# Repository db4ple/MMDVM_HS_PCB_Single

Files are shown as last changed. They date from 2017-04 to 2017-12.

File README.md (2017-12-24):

# MMDVM_HS_PCB_Single
Single Sided PCB for MMDVM Hotspot with RF7021SE module and Blue Pill STM32DUINO

This project provides a simple, singled sided PCB for the [MMDVM_HS Hotspot main repo](https://github.com/juribeparada/MMDVM_HS). 
Can be easily made using toner transfer, has very few wires. Just order the components (RF7021SE from Aliexpress and Blue Pill 
STM32DUINO clone) and put on board. Do not forget to replace the RF7021SE standard oscillator with a supported TCXO.

The second pcb design called stick is much smaller, and has a more logical led layout. But it requires a few more via wires if made as a single sided board. 
Most connecting wires are only used if the optional connectors are used. 
The single pin connector in the middle of the board is in fact a bottom / top ground plane connection for a two sided design. No need to use it on a single sided pcb.

© DB4PLE
Licensed under CC-BY-SA 3.0

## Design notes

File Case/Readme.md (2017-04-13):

This is a simple 3D printable case for the board. Best if printed in something more or less transparent. 
In this case the notification LEDs can be seen easily. 

You can either use the Raspberry Pi Zero lid and base (if you run the hotspot using an RPi Zero W) OR the simple base (if you connect the hotspot to an external computer via USB).

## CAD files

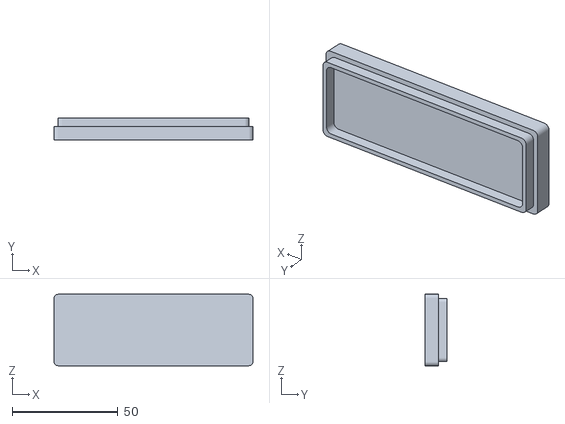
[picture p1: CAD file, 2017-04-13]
Case/Hotspot_base.stl
94.0 x 10.6 x 33.8

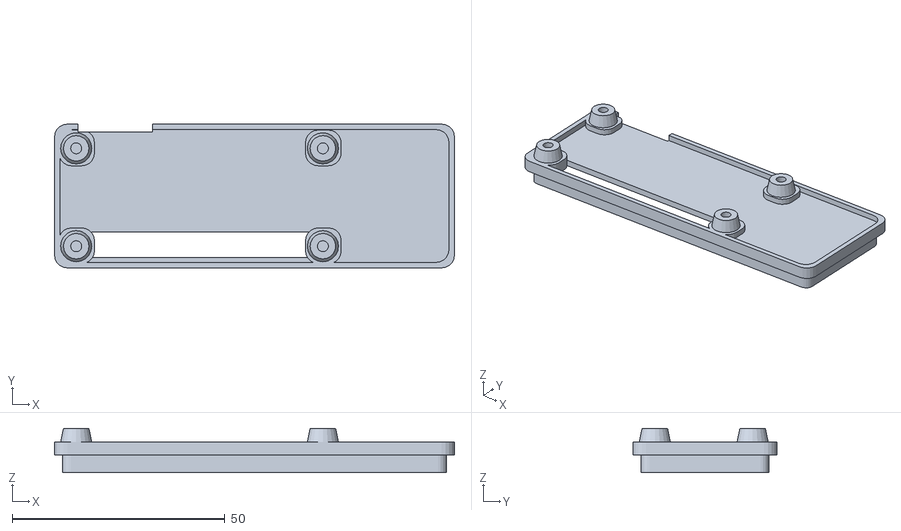
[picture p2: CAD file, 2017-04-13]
Case/Hotspot_RPIZW_lid.stl
94.0 x 33.8 x 10.4

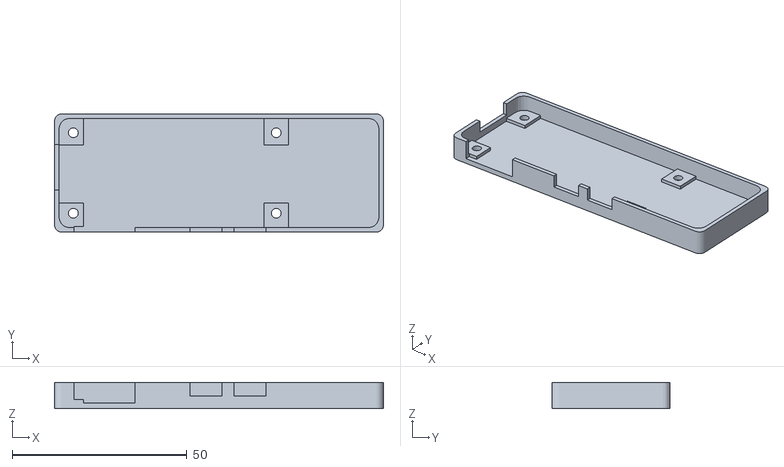
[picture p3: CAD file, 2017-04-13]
Case/Hotspot_RPIZW_base.stl
94.0 x 33.8 x 7.45

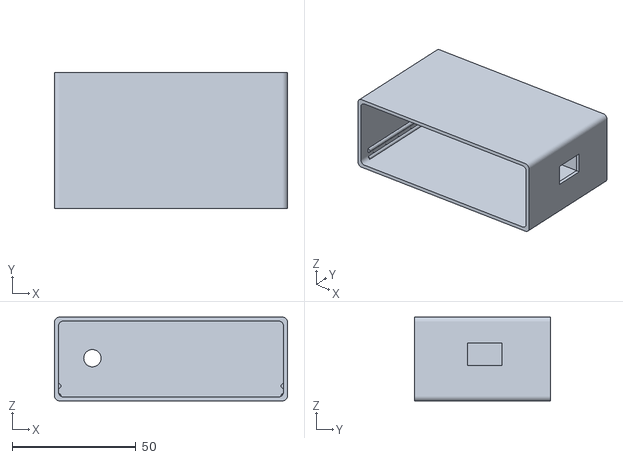
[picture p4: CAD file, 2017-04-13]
Case/Hotspot.stl
94.0 x 54.9 x 33.8

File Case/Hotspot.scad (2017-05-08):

// the rounded cube module comes from
// https://gist.github.com/groovenectar/92174cb1c98c1089347e

$fs = 0.15;


module roundcylinder(d=1,h=10)
{
    translate([0,0,d/2])
    hull()
    {
    sphere(d=d);
    
    translate([0,0,h-d]) sphere(d=d);
    }
}

module roundedcube(size = [1, 1, 1], center = false, radius = 0.5, apply_to = "all") {
	// If single value, convert to [x, y, z] vector
	size = (size[0] == undef) ? [size, size, size] : size;

	translate_min = radius;
	translate_xmax = size[0] - radius;
	translate_ymax = size[1] - radius;
	translate_zmax = size[2] - radius;

	diameter = radius * 2;

	obj_translate = (center == false) ?
		[0, 0, 0] : [
			-(size[0] / 2),
			-(size[1] / 2),
			-(size[2] / 2)
		];

	translate(v = obj_translate) {
		hull() {
			for (translate_x = [translate_min, translate_xmax]) {
				x_at = (translate_x == translate_min) ? "min" : "max";
				for (translate_y = [translate_min, translate_ymax]) {
					y_at = (translate_y == translate_min) ? "min" : "max";
					for (translate_z = [translate_min, translate_zmax]) {
						z_at = (translate_z == translate_min) ? "min" : "max";

						translate(v = [translate_x, translate_y, translate_z])
						if (
							(apply_to == "all") ||
							(apply_to == "xmin" && x_at == "min") || (apply_to == "xmax" && x_at == "max") ||
							(apply_to == "ymin" && y_at == "min") || (apply_to == "ymax" && y_at == "max") ||
							(apply_to == "zmin" && z_at == "min") || (apply_to == "zmax" && z_at == "max")
						) {
							sphere(r = radius);
						} else {
							rotate = 
								(apply_to == "xmin" || apply_to == "xmax" || apply_to == "x") ? [0, 90, 0] : (
								(apply_to == "ymin" || apply_to == "ymax" || apply_to == "y") ? [90, 90, 0] :
								[0, 0, 0]
							);
							rotate(a = rotate)
							cylinder(h = diameter, r = radius, center = true);
						}
					}
				}
			}
		}
	}
}

// end roundedcube contribution


// actual case starts here
// $fn=100;

rpizw_pcb_h = 1.4;
rpizw_pcb_w = 65;
rpizw_pcb_l = 30;

usbpower_offset = 54.0;
usbusb_offset = 41.4;
usb_length = 8.0;
usb_h = 3.0;

hdmi_offset = 12.4;
hdmi_length = 12.0;
hdmi_h = 3.4;




tol = 0.3;
pcb_h = 1.6;
pcb_t = 5;
pcb_w = 48.260;
//pcb_l = 87.860;
pcb_l = 90.86;

stm_h = 11.35;
stm_w = 22.860;
stm_l = 53.430;

stm_usb_w = 14;
stm_usb_h = 9;    
rf_w = 27;    

wall = 1.6;
box_h=30 + 2* tol;
down=-13.5;

extend_h = 32;


module holder()
{
    dia = 2;
    translate([pcb_l,0,-dia/2-0.4]) rotate([270,0,0]) cylinder(d=2,h=pcb_w + wall);
    translate([0,0,-dia/2-0.4]) rotate([270,0,0]) cylinder(d=2,h=pcb_w + wall);
    
    translate([pcb_l,0,dia/2+pcb_h]) rotate([270,0,0]) cylinder(d=2,h=pcb_w + wall);
    translate([0,0,dia/2+pcb_h]) rotate([270,0,0]) cylinder(d=2,h=pcb_w + wall);

}
module pcb()
{
    cube([pcb_l,pcb_w,pcb_h]);
}
module rf7021()
{
    rf_pcb_h = 1;
    ant_dia = 7;
    sma_pin_dia = 1.25;
    translate([-rf_w/2,0,0])cube([rf_w,pcb_w,rf_pcb_h]);
    translate([0,35,rf_pcb_h+sma_pin_dia/2]) rotate([270,0,0]) cylinder(d=ant_dia,h=30);
}

module stm()
{
    cube([stm_l,stm_w,stm_h]);
    translate([stm_l-2,(stm_w-stm_usb_w)/2 ,stm_h-stm_usb_h/2+2.5]) cube([20,stm_usb_w,stm_usb_h]);   
}

module hotspot()
{
    pcb();
    translate([12.7+1,0,pcb_h+10.6])rf7021();
    translate([pcb_l - stm_l,(pcb_w-stm_w)/2,pcb_h]) stm();
}




//translate([-wall,-wall,-wall]) cube([pcb_l+2*wall,pcb_w+2*wall,box_h+wall]);
// hotspot();
// rf7021();
// stm();

module assembly()
{

    translate([-pcb_l/2,-pcb_w/2+wall/2+extend_h/2,down]) 
    {
           // hotspot();    

        holder();
    }

    difference()
    {
        color("Orange")
        translate([0,wall,0]) roundedcube([pcb_l+2*wall, pcb_w+wall+extend_h, box_h+2*wall], true, 2, "y");
   
        {
        roundedcube([pcb_l, pcb_w+wall+extend_h, box_h], true, 2, "y");
        translate([-pcb_l/2,-pcb_w/2+extend_h/2+wall/2,down]) 
        {
            hotspot();    
        }
        
    //    translate([0,-10,0]) cube([pcb_l-2,pcb_w+10,box_h-wall]);
        }
    }
}


module assembly_base()
{
    base_h = 3.6;
    color("Orange")
    // translate([0,-wall/2,0]) roundedcube([pcb_l+2*wall, wall, box_h+2*wall], true, 2, "y");    
    difference() {
    translate([0,base_h/2,0]) roundedcube([pcb_l-2*tol, base_h, box_h-2*tol], true, 2, "y");
    translate([0,base_h/2,0]) roundedcube([pcb_l-wall-2*tol, base_h+5, box_h-wall-2*tol], true, 2, "y");
    }
}

// translate([(pcb_l-2*tol)/2+tol,(box_h-2*tol)/2+tol,-4.7]) rotate ([90,0,0]) assembly_base();



module pizw()
{

    difference()
    {
        cube([30,65,rpizw_pcb_h]);
        translate([0,0,-0.1])
        {    
            translate([3.5,3.5]) cylinder(d=2.75,h=4);
            translate([rpizw_pcb_l-3.5,3.5]) cylinder(d=2.75,h=4);
            translate([rpizw_pcb_l-3.5,rpizw_pcb_w-3.5]) cylinder(d=2.75,h=4);
            translate([3.5,rpizw_pcb_w-3.5]) cylinder(d=2.75,h=4);
        }
    }
translate([-3,rpizw_pcb_w-usbusb_offset-usb_length/2-tol,rpizw_pcb_h-0.2]) cube([10,usb_length+2*tol,usb_h+2*tol]);
translate([-3,rpizw_pcb_w-usbpower_offset-usb_length/2-tol,rpizw_pcb_h-0.2]) cube([10,usb_length+2*tol,usb_h+2*tol]);
translate([-3,rpizw_pcb_w-hdmi_offset-hdmi_length/2,rpizw_pcb_h-0.2]) cube([10,hdmi_length,hdmi_h+2*tol]);
}

module pizw_holder()
{
    dia = 2;
    translate([-rpizw_pcb_w/2,0,-30/2])
    {
        translate([0,-dia/2],0) rotate([90,0,90]) roundcylinder(d=dia,h=rpizw_pcb_w);
        translate([0,rpizw_pcb_h+dia/2],0) rotate([90,0,90]) roundcylinder(d=dia,h=rpizw_pcb_w);
    }
    translate([-rpizw_pcb_w/2,0,30/2])
    {
        translate([0,-dia/2],0) rotate([90,0,90]) roundcylinder(d=dia,h=19);
        translate([36,-dia/2],0) rotate([90,0,90]) roundcylinder(d=dia,h=29);
        // translate([21,rpizw_pcb_h+dia/2],0) rotate([90,0,90]) roundcylinder(d=dia,h=5);
        translate([rpizw_pcb_w-5,rpizw_pcb_h+dia/2],0) rotate([90,0,90]) roundcylinder(d=dia,h=5);
        translate([0,rpizw_pcb_h+dia/2],0) rotate([90,0,90]) roundcylinder(d=dia,h=5);
    }
    
    // translate([pcb_l,0,dia/2+pcb_h]) rotate([270,0,0]) cylinder(d=2,h=pcb_w + wall);
    // translate([0,0,dia/2+pcb_h]) rotate([270,0,0]) cylinder(d=2,h=pcb_w + wall);

}


module all()
{
    rpizw_down = 2;
    difference()
    {
        union()
        {
            assembly();
            translate([0,-box_h-rpizw_down,0])    pizw_holder();
        }
    translate([0,-box_h-rpizw_down,0])
    {
        translate([rpizw_pcb_w/2,0,rpizw_pcb_l/2])rotate([0,90,90]) color("red") pizw();
    }
}

}


difference()
{
    all();
//    translate([-50,-23,-60])cube([100,200,100]);
}

// pizw();

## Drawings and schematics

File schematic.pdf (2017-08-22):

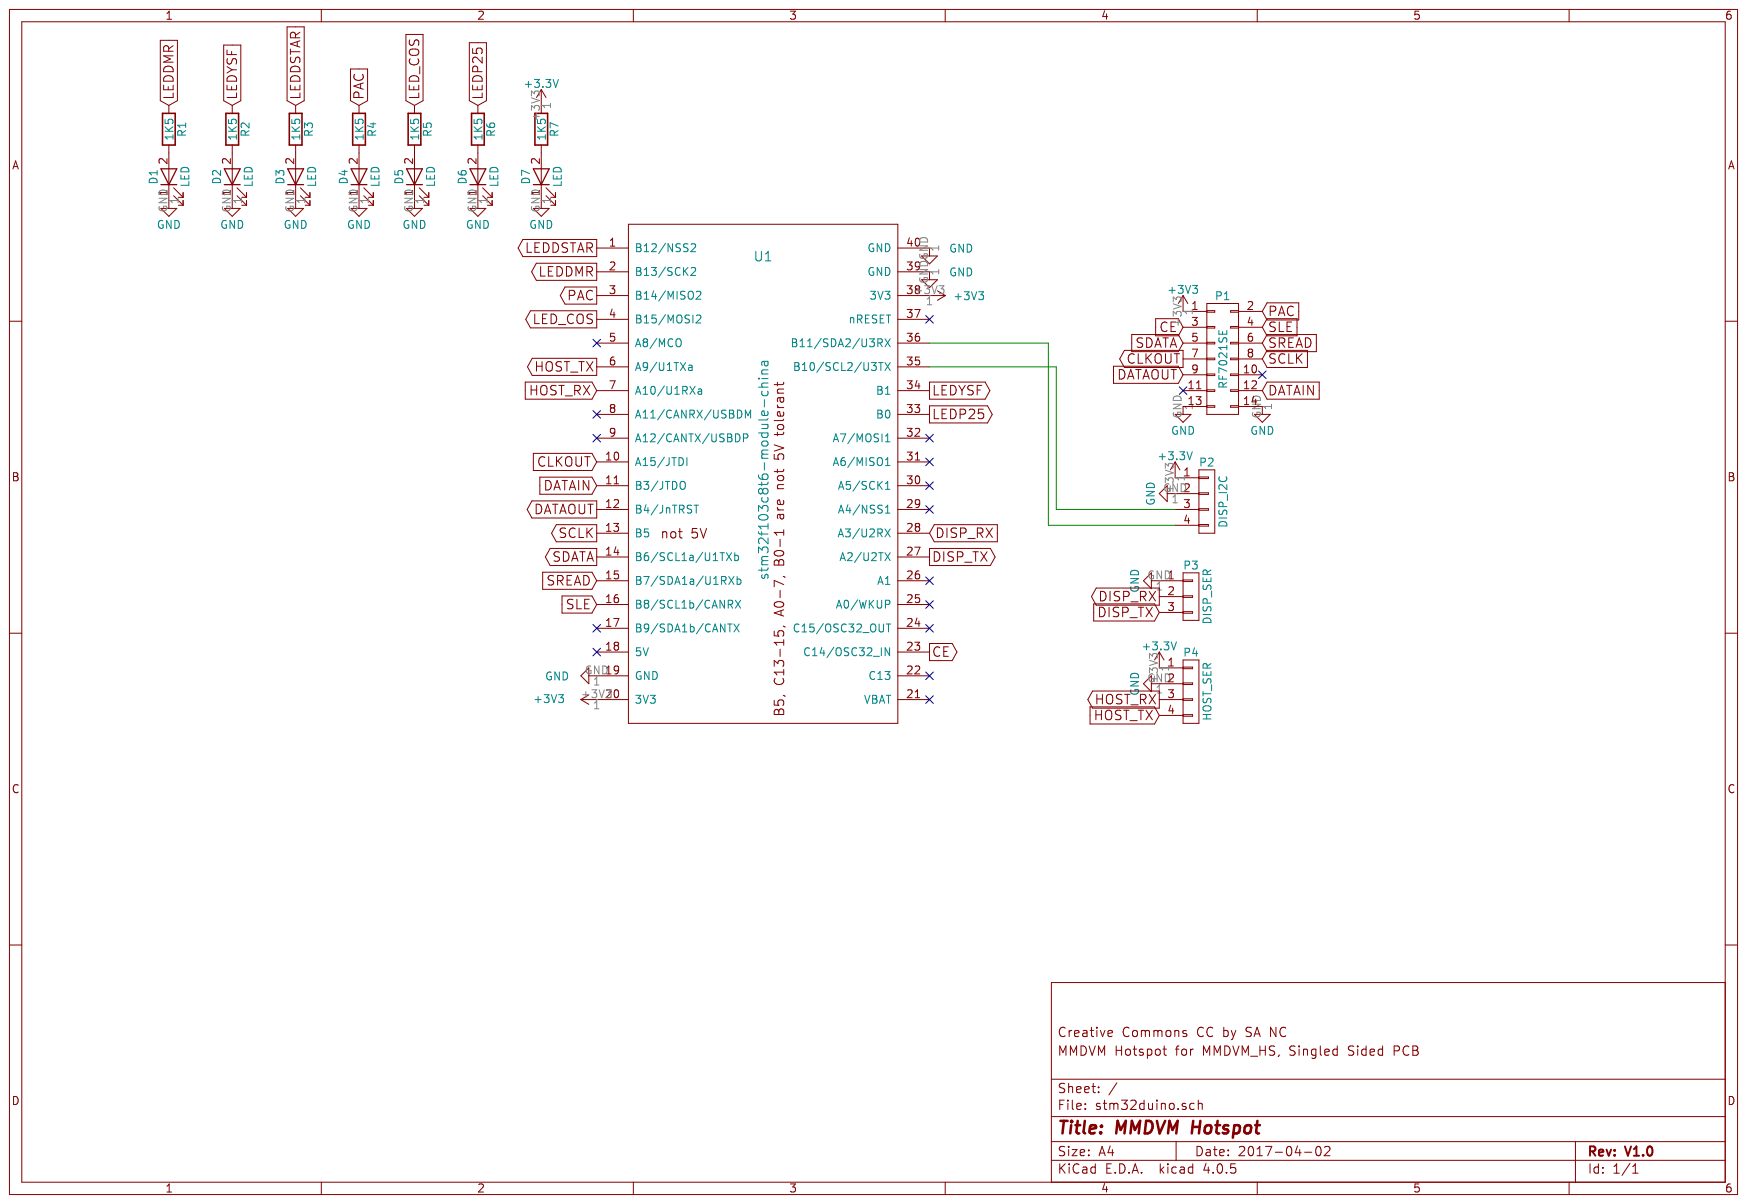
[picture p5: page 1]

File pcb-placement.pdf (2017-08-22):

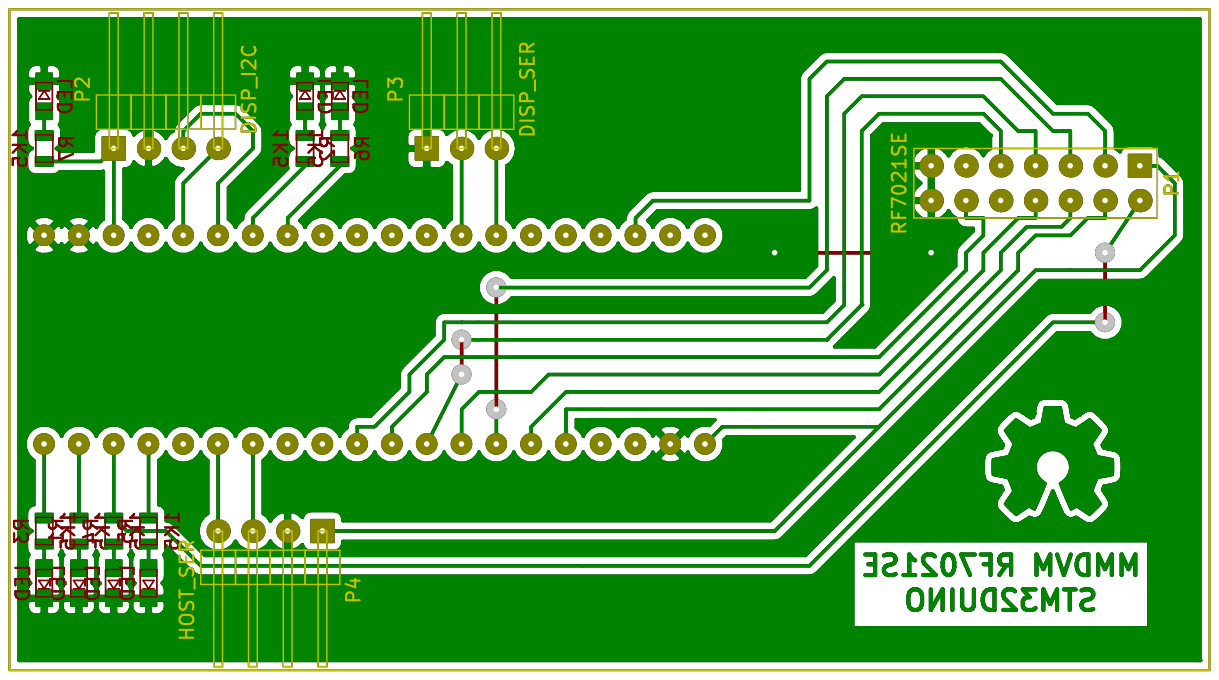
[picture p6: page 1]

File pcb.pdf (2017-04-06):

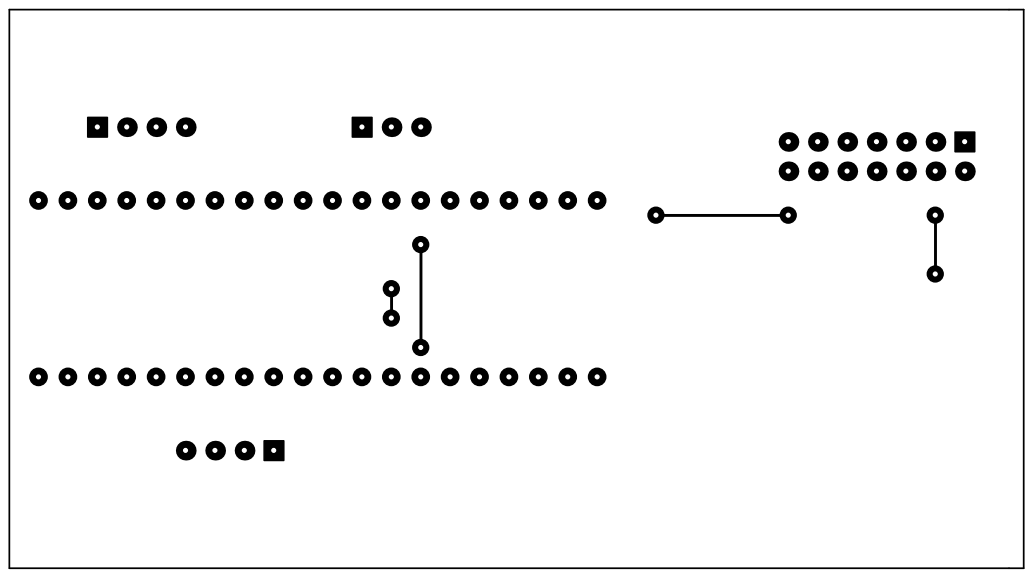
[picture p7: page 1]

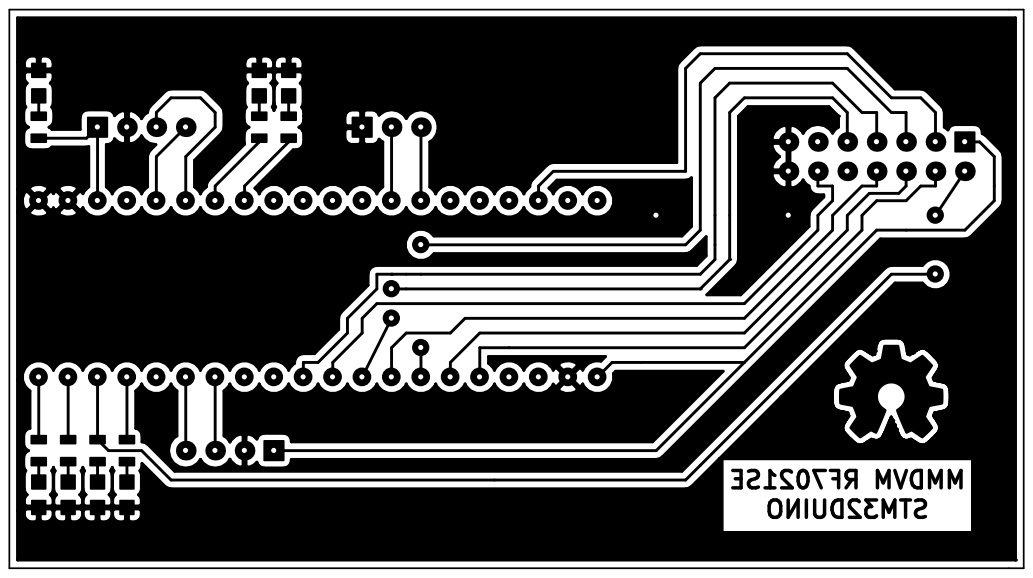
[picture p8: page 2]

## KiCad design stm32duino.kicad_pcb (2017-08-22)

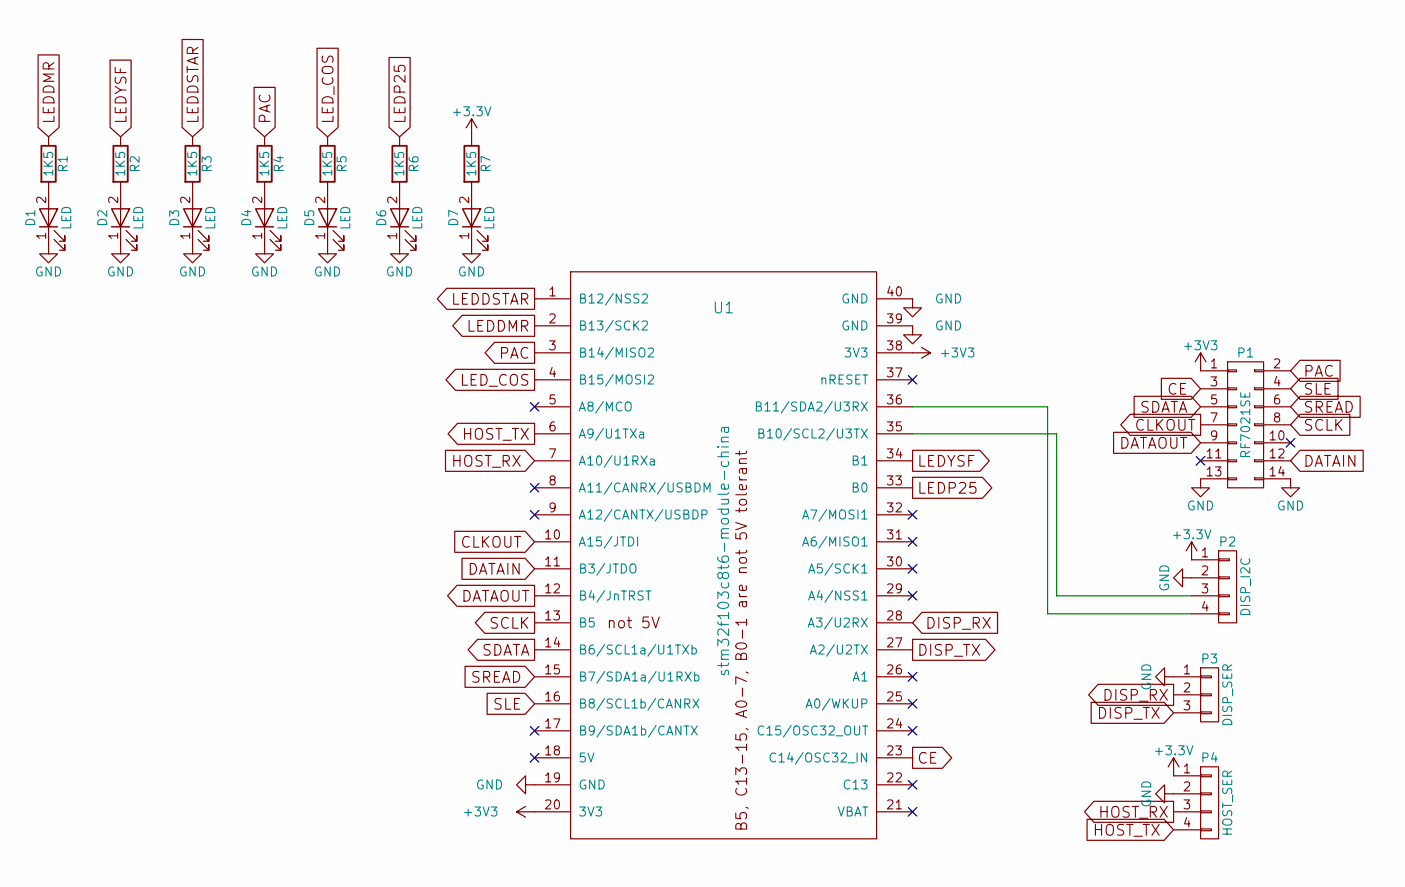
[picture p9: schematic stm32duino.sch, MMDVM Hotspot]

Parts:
D1, D2, D3, D4, D5, D6, D7: LED; LED_0805
P1: RF7021SE; Pin_Header_Straight_2x07_Pitch2.54mm
P2: DISP_I2C; Pin_Header_Angled_1x04_Pitch2.54mm
P3: DISP_SER; Pin_Header_Angled_1x03_Pitch2.54mm
P4: HOST_SER; Pin_Header_Angled_1x04_Pitch2.54mm
R1, R2, R3, R4, R5, R6, R7: 1K5; R_0805
U1: stm32f103c8t6-module-china

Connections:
CE: P1.3, U1.23 (C14/OSC32_IN)
CLKOUT: P1.7, U1.10 (A15/JTDI)
DATAIN: P1.12, U1.11 (B3/JTDO)
DATAOUT: P1.9, U1.12 (B4/JnTRST)
DISP_RX: P3.2, U1.28 (A3/U2RX)
DISP_TX: P3.3, U1.27 (A2/U2TX)
GND: D1.1 (K), D2.1 (K), D3.1 (K), D4.1 (K), D5.1 (K), D6.1 (K), D7.1 (K), P1.13, P1.14, P2.2, P3.1, P4.2, U1.19 (GND), U1.39 (GND), U1.40 (GND)
HOST_RX: P4.3, U1.7 (A10/U1RXa)
HOST_TX: P4.4, U1.6 (A9/U1TXa)
LEDDMR: R1.1, U1.2 (B13/SCK2)
LEDDSTAR: R3.1, U1.1 (B12/NSS2)
LEDP25: R6.1, U1.33 (B0)
LEDYSF: R2.1, U1.34 (B1)
LED_COS: R5.1, U1.4 (B15/MOSI2)
unnamed: D1.2 (A), R1.2
unnamed: D2.2 (A), R2.2
unnamed: D3.2 (A), R3.2
unnamed: D4.2 (A), R4.2
unnamed: D5.2 (A), R5.2
unnamed: D6.2 (A), R6.2
unnamed: D7.2 (A), R7.2
unnamed: P2.3, U1.35 (B10/SCL2/U3TX)
unnamed: P2.4, U1.36 (B11/SDA2/U3RX)
PAC: P1.2, R4.1, U1.3 (B14/MISO2)
SCLK: P1.8, U1.13 (B5)
SDATA: P1.5, U1.14 (B6/SCL1a/U1TXb)
SLE: P1.4, U1.16 (B8/SCL1b/CANRX)
SREAD: P1.6, U1.15 (B7/SDA1a/U1RXb)

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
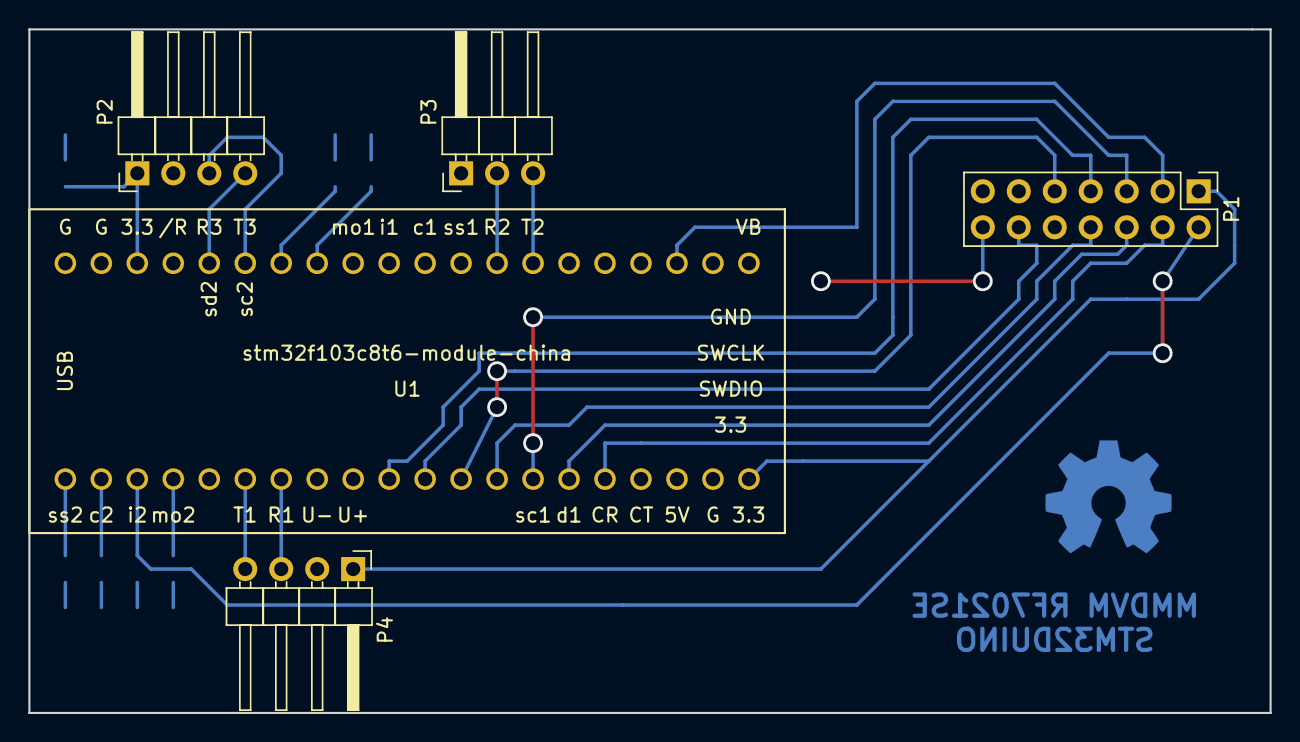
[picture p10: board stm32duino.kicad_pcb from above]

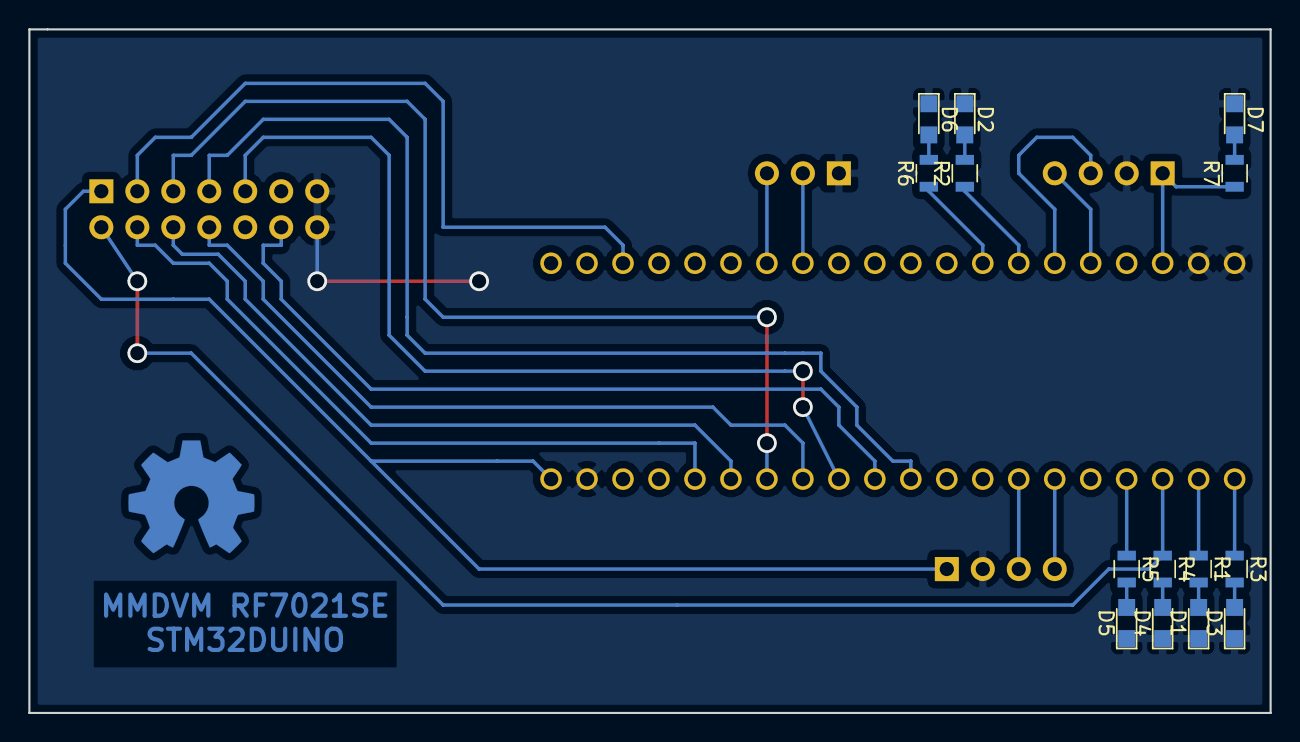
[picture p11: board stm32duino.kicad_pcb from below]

Board: 2 copper layers, 87.6 x 48.3 mm, 19 parts (14 on the bottom side), 29 nets.

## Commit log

2017-04-06 Minor beautification, added OSHW logo to PCB
    [stm32duino.kicad_pcb, stm32duino.sch]
2017-04-06 Added case design
    [Hotspot.scad, Hotspot.stl]
2017-04-13 Added some more case components including a base containing an Pi Zero W which makes a nice selfcontained Hotspot.
    The additional PCB design is much smaller (a bit longer, though) and
    can be used to build a fairly compact hotspot. No case yet, not even build yet.
    [Hotspot.scad, Hotspot.stl, Hotspot_RPIZW_base.stl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]
2017-05-08 Changed case to hold RPI Zero internally. Case may be a little to wide for machined boards, in this case adjust pcb_l after test print of some millimeters of height.
    [Hotspot.scad, stick.kicad_pcb]
2017-08-22 Added placement and schematic pdf
    [stm32duino.kicad_pcb]
2017-12-23 Added smaller footprint board which is NOT singlesided if you want the serial display or I2C display However, very few simple wires will do the job if you don't have the ability to do a two sided PCB.
    [stick.kicad_pcb]
2017-12-24 Finalized new "stick" design. Added gerbers.
    [stick-B.Cu.gbl, stick-B.Mask.gbs, stick-B.SilkS.gbo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]

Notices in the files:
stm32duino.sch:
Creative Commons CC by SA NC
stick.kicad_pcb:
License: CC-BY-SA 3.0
